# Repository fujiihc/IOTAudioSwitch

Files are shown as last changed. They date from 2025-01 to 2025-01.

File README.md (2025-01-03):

# IOTAudioSwitch
Google Home Compatible Audio Input Selector

## Overview
I created this switcher because I have too many audio inputs (CD Player, Turntable, Google Chromecast Audio), and only one set of speakers.

I also had recently acquired a Google Home Nest and wanted to experiment with ESP32 Dev Boards.

I found that using Google Home to control input switching was way more convenient than having to get up and manually plug things into my speakers.

The switching is done with a [CD4052B Multiplexor](https://www.ti.com/lit/ds/symlink/cd4052b.pdf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).
## Future Plans
Create a version WITHOUT Arduino Cloud using different [ESP32 Microcontroller](https://www.amazon.com/DORHEA-Development-Microcontroller-NodeMCU-32S-ESP-WROOM-32/dp/B086MJGFVV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)

Look into Independent Power Supplies/Power Filtering

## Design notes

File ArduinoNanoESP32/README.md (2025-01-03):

# IOTAudioSwitch using Arduino Nano ESP32

## Overview
This version of the IOTAudioSwitch uses an Arduino Nano ESP32 as the microcontroller.

It is compatible with Google Home through [Arduino Cloud](https://cloud.arduino.cc/).
## Set Up

## Notes
The Schematic and PCB include traces connecting Pin 3 to INH.
This is never actually used for "Mute" functionality.
This can be removed and ignored due to Arduino Cloud "Cloud Variable" limitations.

## To-Do/Future Plans
Finish Custom PCB

Finish "Set Up" in README

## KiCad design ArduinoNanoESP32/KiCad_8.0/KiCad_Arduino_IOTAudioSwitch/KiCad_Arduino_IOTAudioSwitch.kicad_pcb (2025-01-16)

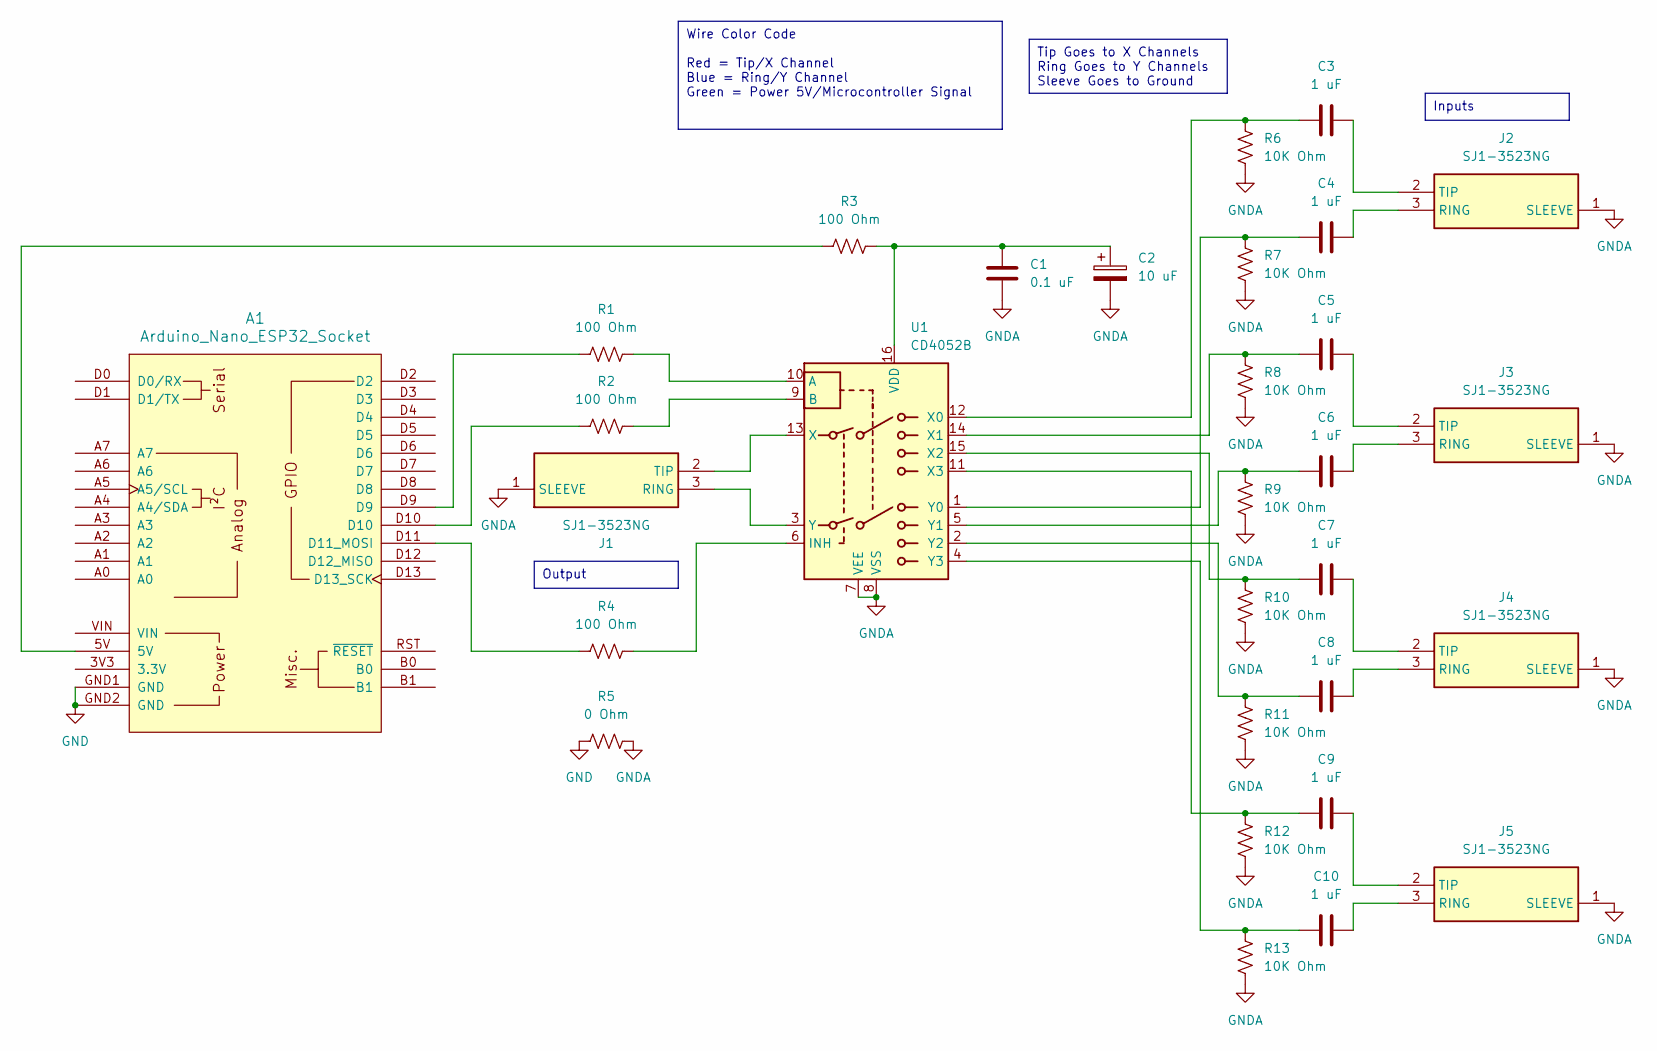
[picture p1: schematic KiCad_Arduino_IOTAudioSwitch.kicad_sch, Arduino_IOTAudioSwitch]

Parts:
A1: Arduino_Nano_ESP32_Socket
C1: 0.1 uF; C_Disc_D8.0mm_W2.5mm_P5.00mm
C2: 10 uF; CP_Radial_D5.0mm_P2.00mm
C3, C4, C5, C6, C7, C8, C9, C10: 1 uF; C_Disc_D8.0mm_W2.5mm_P5.00mm
J1, J2, J3, J4, J5: SJ1-3523NG; SJ13523NG; Mouser Part Number 490-SJ1-3523NG
R1, R2, R3, R4: 100 Ohm; R_Axial_DIN0207_L6.3mm_D2.5mm_P7.62mm_Horizontal
R5: 0 Ohm; R_Axial_DIN0207_L6.3mm_D2.5mm_P7.62mm_Horizontal
R6, R7, R8, R9, R10, R11, R12, R13: 10K Ohm; R_Axial_DIN0207_L6.3mm_D2.5mm_P7.62mm_Horizontal
U1: CD4052B; DIPS762W70P254L2032H510Q16N

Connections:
GND: A1.GND1 (GND), A1.GND2 (GND), R5.1
GNDA: C1.2, C2.2, J1.1 (SLEEVE), J2.1 (SLEEVE), J3.1 (SLEEVE), J4.1 (SLEEVE), J5.1 (SLEEVE), R5.2, R6.2, R7.2, R8.2, R9.2, R10.2, R11.2, R12.2, R13.2, U1.7 (VEE), U1.8 (VSS)
unnamed: A1.D11 (D11_MOSI), R4.1
unnamed: A1.5V, R3.1
unnamed: A1.D9, R1.1
unnamed: A1.D10, R2.1
unnamed: J1.3 (RING), U1.3 (Y)
unnamed: J1.2 (TIP), U1.13 (X)
unnamed: C4.2, J2.3 (RING)
unnamed: C3.2, J2.2 (TIP)
unnamed: C6.2, J3.3 (RING)
unnamed: C5.2, J3.2 (TIP)
unnamed: C8.2, J4.3 (RING)
unnamed: C7.2, J4.2 (TIP)
unnamed: C10.2, J5.3 (RING)
unnamed: C9.2, J5.2 (TIP)
unnamed: R1.2, U1.10 (A)
unnamed: R2.2, U1.9 (B)
unnamed: R4.2, U1.6 (INH)
unnamed: C1.1, C2.1, R3.2, U1.16 (VDD)
unnamed: C3.1, R6.1, U1.12 (X0)
unnamed: C5.1, R8.1, U1.14 (X1)
unnamed: C7.1, R10.1, U1.15 (X2)
unnamed: C9.1, R12.1, U1.11 (X3)
unnamed: C4.1, R7.1, U1.1 (Y0)
unnamed: C6.1, R9.1, U1.5 (Y1)
unnamed: C8.1, R11.1, U1.2 (Y2)
unnamed: C10.1, R13.1, U1.4 (Y3)

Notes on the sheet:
Wire Color Code Red = Tip/X Channel Blue = Ring/Y Channel Green = Power 5V/Microcontroller Signal
Output
Tip Goes to X Channels Ring Goes to Y Channels Sleeve Goes to Ground
Inputs

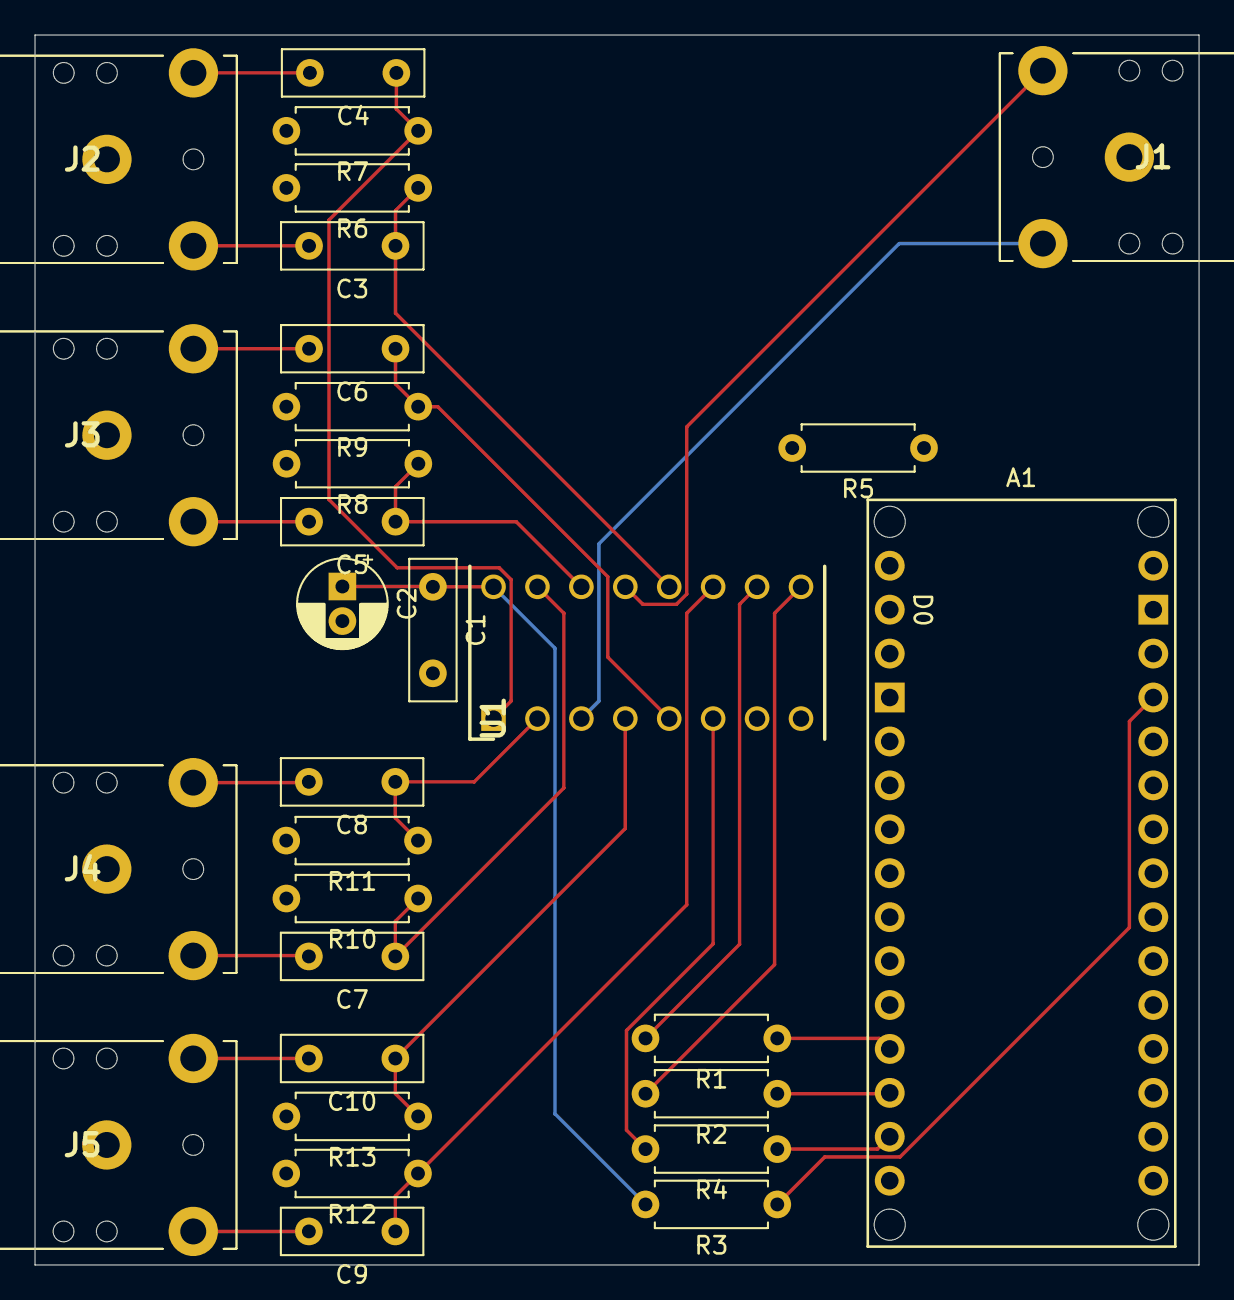
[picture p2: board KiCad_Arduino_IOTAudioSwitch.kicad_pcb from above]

Board: 2 copper layers, 67.3 x 71.1 mm, 30 parts (0 on the bottom side), 28 nets.

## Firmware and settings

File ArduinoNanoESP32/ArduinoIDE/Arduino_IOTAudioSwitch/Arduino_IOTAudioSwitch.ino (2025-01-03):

/*
Author: Hiro Fujii
Date: 04Jul24
*/

#include "arduino_secrets.h"
#include "thingProperties.h"

//A, B, C Pins for Multiplexor
//Make These Whatever You Want According To Your Schematic
const int A = 2;
const int B = 3;
const int C = 4;
//C Doesn't Have Mute Functionality Currently Bc Of Arduino Cloud Limitations

//Setup
void setup(){
  initProperties();
  ArduinoCloud.begin(ArduinoIoTPreferredConnection);

  //Preps Output Pins
  pinMode(A, OUTPUT);
  pinMode(B, OUTPUT);
  pinMode(C, OUTPUT);
  
  //Updates to Previously Selected Channel On Boot
  onChannelChange();
}

//Loop
void loop(){
  ArduinoCloud.update();
}

//When Cloud Variable channel Changes
//Handles Actual Switching of Channels
void onChannelChange(){ 
  if(channel == 1){
    digitalWrite(A, LOW);
    digitalWrite(B, LOW);
  }else if(channel == 2){
    digitalWrite(A, HIGH);
    digitalWrite(B, LOW);
  }else if(channel == 3){
    digitalWrite(A, LOW);
    digitalWrite(B, HIGH);
  }else if(channel == 4){
    digitalWrite(A, HIGH);
    digitalWrite(B, HIGH);
  }
}

//The Following Functions Handle How Google Home Interacts With Changing Channels

//When Cloud Variable audioChannel1 Changes
void onAudioChannel1Change()  {
  if(audioChannel1 == true){
    channel = 1;
    audioChannel2 = false;
    audioChannel3 = false;
    audioChannel4 = false;
    onChannelChange();
  }
}

//When Cloud Variable audioChannel2 Changes
void onAudioChannel2Change()  {
  if(audioChannel2 == true){
      channel = 2;
      audioChannel1 = false;
      audioChannel3 = false;
      audioChannel4 = false;
      onChannelChange();
  }
}

//When Cloud Variable audioChannel3 Changes
void onAudioChannel3Change()  {
  if(audioChannel3 == true){
    channel = 3;
    audioChannel2 = false;
    audioChannel1 = false;
    audioChannel4 = false;
    onChannelChange();
  }
}

//When Cloud Variable audioChannel4 Changes
void onAudioChannel4Change()  {
  if(audioChannel4 == true){
    channel = 4;
    audioChannel2 = false;
    audioChannel3 = false;
    audioChannel1 = false;
    onChannelChange();
  }
}

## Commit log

2025-01-03 Added Arduino Code
2025-01-03 Added KiCad and Arduino Files
    [KiCad_Arduino_IOTAudioSwitch.kicad_pcb, KiCad_Arduino_IOTAudioSwitch.kicad_sch]
2025-01-16 Created PCB
    [KiCad_Arduino_IOTAudioSwitch.kicad_pcb, KiCad_Arduino_IOTAudioSwitch.kicad_sch]
